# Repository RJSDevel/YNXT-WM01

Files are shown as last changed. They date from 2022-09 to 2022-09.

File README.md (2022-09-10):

# YNXT-WM01
Zigbee Water meter device for YF-S402B counter

The device was created for counting flow and volume passed through kitchen water filter, and it has three independent count channels for measurement, also has buzzer for remind to change filters and extranal load MOSFET for e.g unleak valve enable 
Zigbee2Mqtt supported by [External convector](/YNXT-WM-01.js)

## Z2M and HA Views
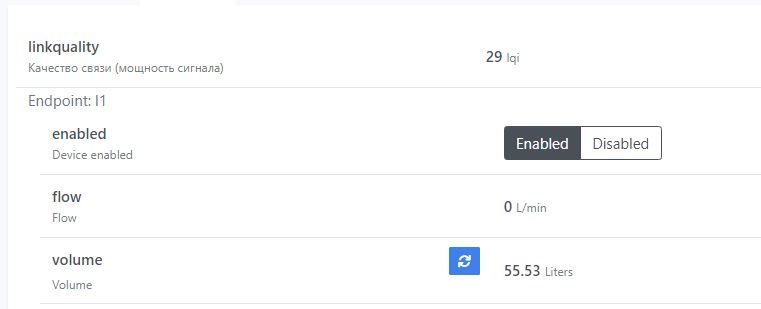
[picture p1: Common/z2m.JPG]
Z2m device

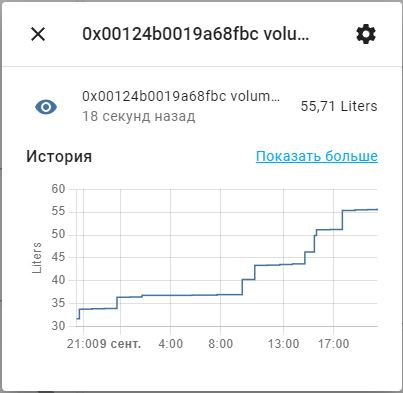
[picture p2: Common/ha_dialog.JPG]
HA Volume Dialog

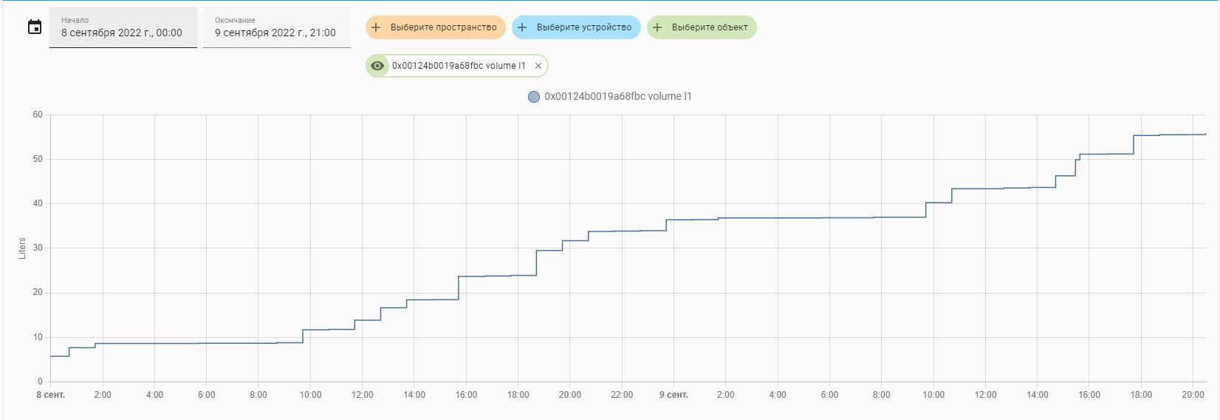
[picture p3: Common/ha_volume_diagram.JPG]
HA Volume Diagram

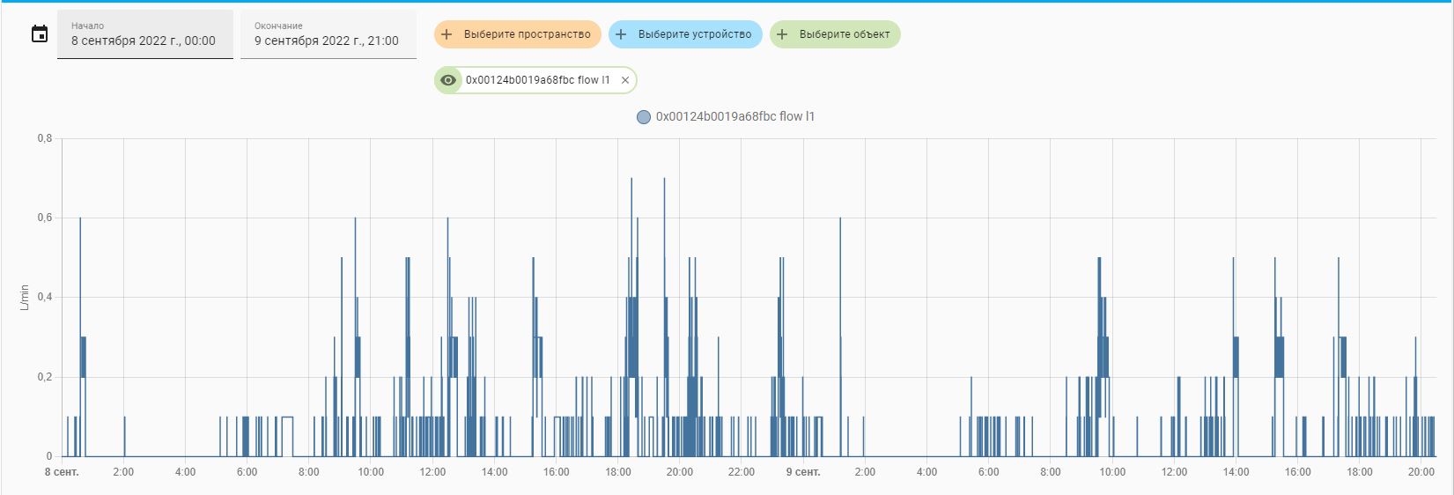
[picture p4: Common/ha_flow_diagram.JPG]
HA Flow Diagram

## Scheme
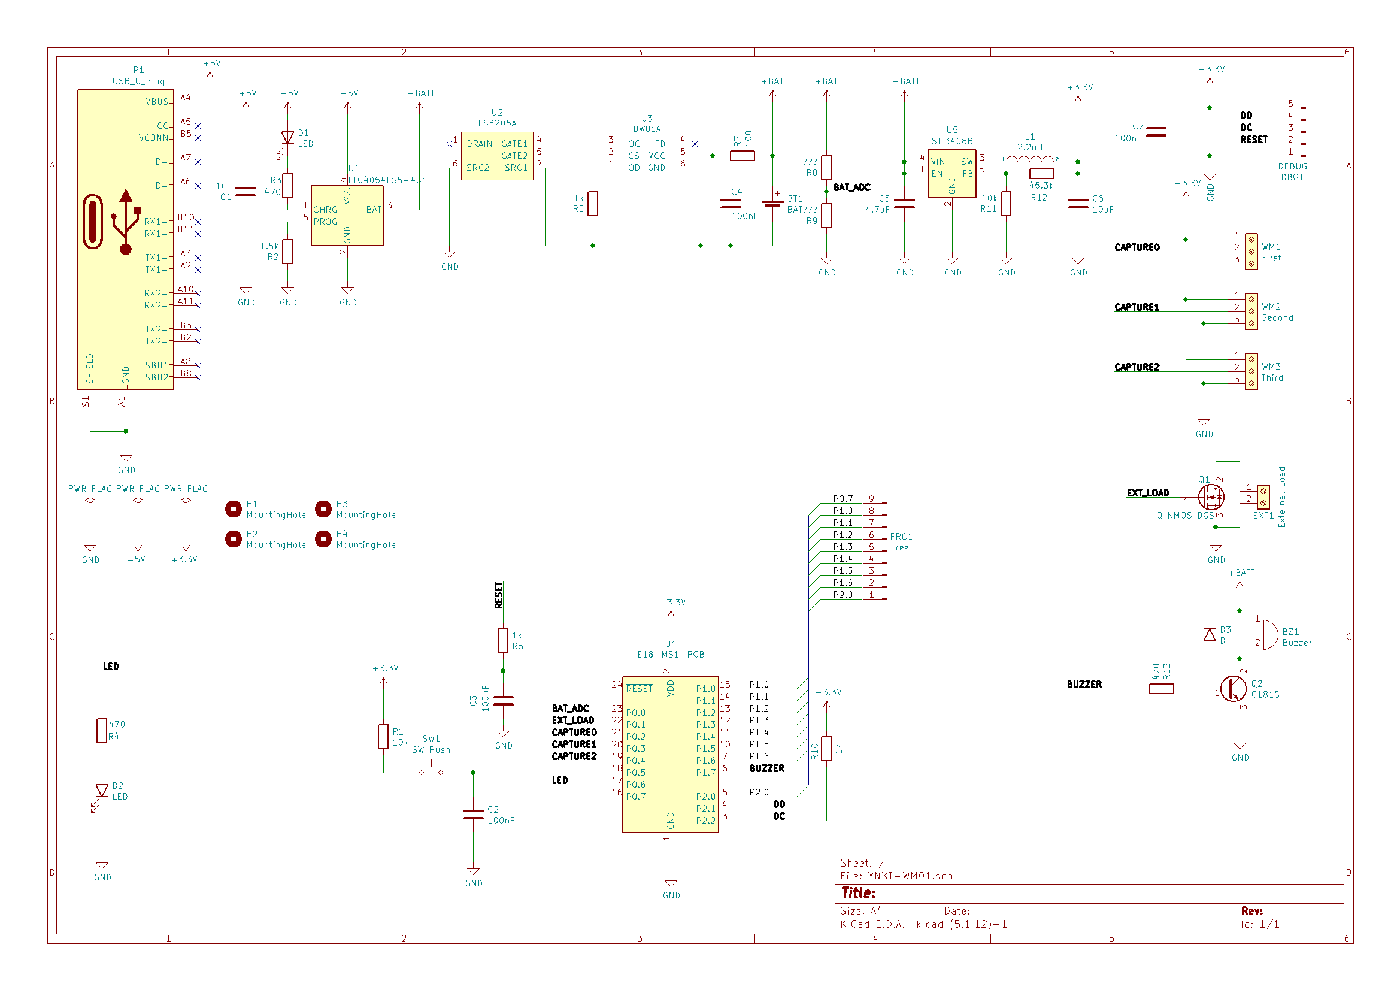
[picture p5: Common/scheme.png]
Scheme

Top
Bottom

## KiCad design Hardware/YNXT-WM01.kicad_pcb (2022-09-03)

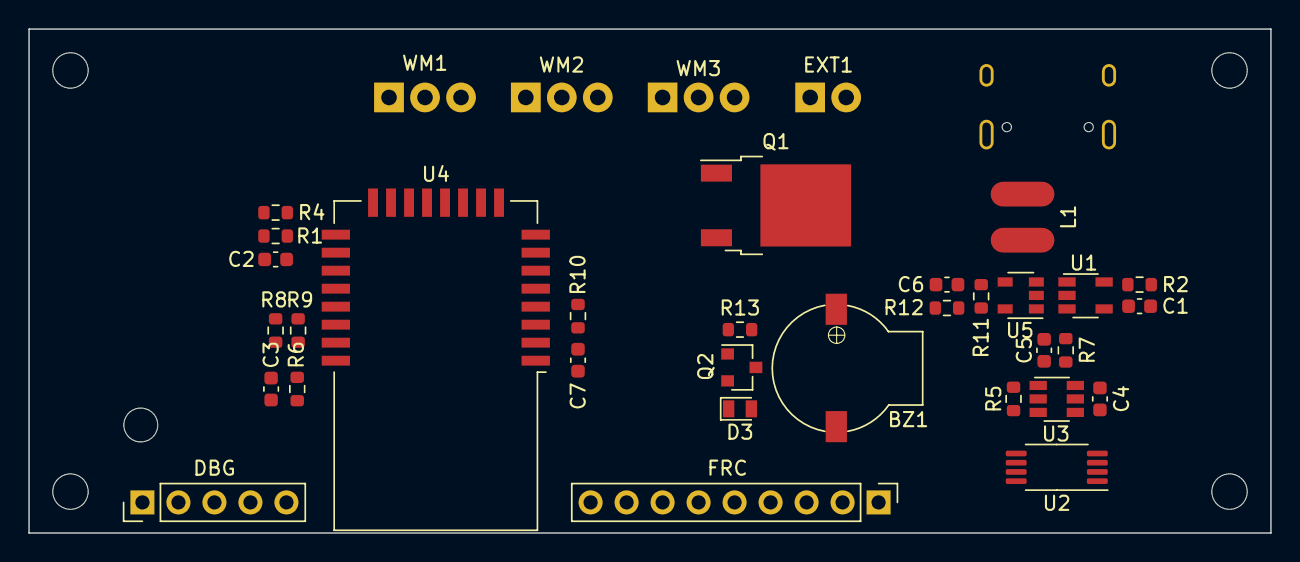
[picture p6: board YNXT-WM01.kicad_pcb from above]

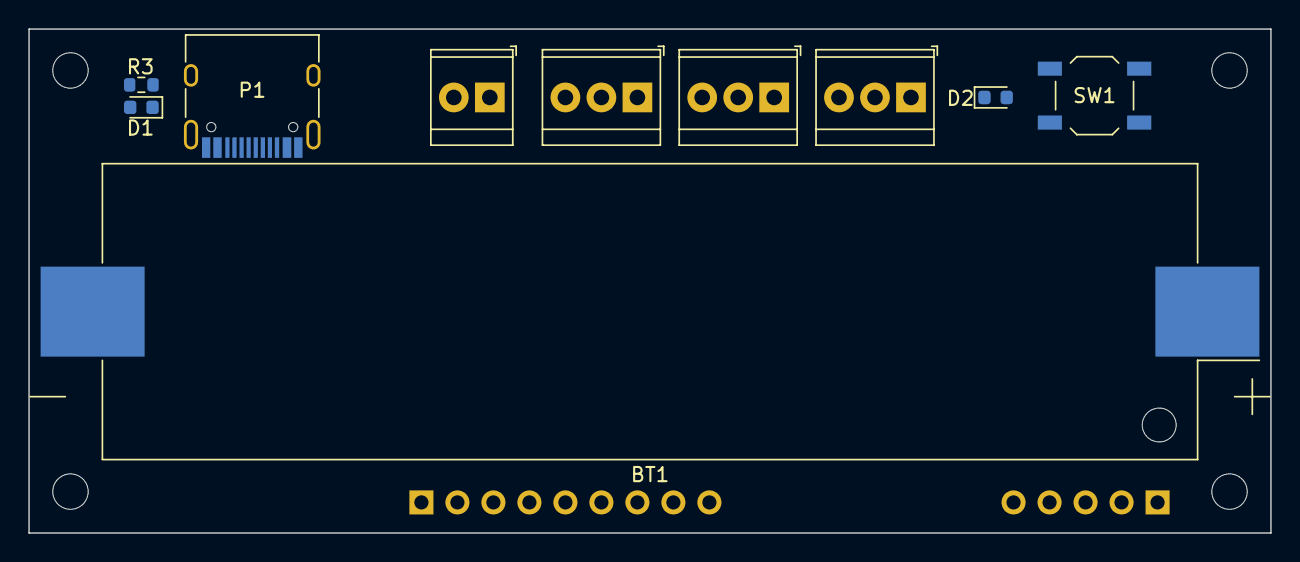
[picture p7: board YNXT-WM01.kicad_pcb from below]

Board: 2 copper layers, 87.6 x 35.6 mm, 45 parts (10 on the bottom side), 41 nets, no tracks yet.

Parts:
BT1: BAT; BatteryHolder_Blossom_1042_1x18650
BZ1: Buzzer; MLT-9032
C1: 1uF; C_0603_1608Metric
C2, C3, C4, C7: 100nF; C_0603_1608Metric
C5: 4.7uF; C_0603_1608Metric
C6: 10uF; C_0603_1608Metric
D1, D2: LED; LED_0603_1608Metric
D3: D; D_MicroMELF
DBG: DEBUG; PinHeader_1x05_P2.54mm_Vertical
EXT1: External Load; TerminalBlock_TE_282834-2_1x02_P2.54mm_Horizontal
FRC: Free; PinHeader_1x09_P2.54mm_Vertical
H1, H2, H3, H4: MountingHole; MountingHole_2.5mm
L1: 2.2uH; CD43
P1: USB_C_Plug; USB_C_Receptacle_HRO_TYPE-C-31-M-12
Q1: Q_NMOS_DGS; TO-252-2
Q2: Q_NPN_BCE; SOT-23
R1, R11: 10k; R_0603_1608Metric
R2: 1.65k; R_0603_1608Metric
R3, R4: 500; R_0603_1608Metric
R5, R6, R10: 1k; R_0603_1608Metric
R7: 100; R_0603_1608Metric
R8, R9: ???; R_0603_1608Metric
R12: 45.3k; R_0603_1608Metric
R13: 470; R_0603_1608Metric
SW1: SW_Push; SW_SPST_TL3342
U1: LTC4054ES5-4.2; TSOT-23-5
U2: FS8205A; TSSOP-8_4.4x3mm_P0.65mm
U3: DW01A; TSOT-23-6
U4: E18-MS1-PCB
U5: STI3408B; SOT-23-5
WM1: First; TerminalBlock_TE_282834-3_1x03_P2.54mm_Horizontal
WM2: Second; TerminalBlock_TE_282834-3_1x03_P2.54mm_Horizontal
WM3: Third; TerminalBlock_TE_282834-3_1x03_P2.54mm_Horizontal

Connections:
+3V3: C6.1, C7.1, DBG.5, L1.2, R1.1, R10.2, R12.2, U4.2, WM1.1, WM2.1, WM3.1
+5V: C1.2, P1.A4, P1.A9, P1.B4, P1.B9, R3.1, U1.4
+BATT: BT1.1, BZ1.1, C5.1, D3.1, R7.2, R8.2, U1.3, U5.1, U5.4
/BAT_ADC: R8.1, R9.2, U4.23
/BUZZER: R13.2, U4.6
/CAPTURE0: U4.21, WM1.2
/CAPTURE1: U4.20, WM2.2
/CAPTURE2: U4.19, WM3.2
/DC: DBG.3, R10.1, U4.3
/DD: DBG.4, U4.4
/EXT_LOAD: Q1.1, U4.22
/KEY: C2.1, SW1.2, U4.18
/LED: R4.2, U4.17
/P0.7: FRC.9, U4.16
/P1.0: FRC.8, U4.15
/P1.1: FRC.7, U4.14
/P1.2: FRC.6, U4.13
/P1.3: FRC.5, U4.12
/P1.4: FRC.4, U4.11
/P1.5: FRC.3, U4.10
/P1.6: FRC.2, U4.7
/P2.0: FRC.1, U4.5
/RESET: DBG.2, R6.2
GND: C1.1, C2.2, C3.1, C5.2, C6.2, C7.2, D2.1, DBG.1, EXT1.2, P1.A1, P1.A12, P1.B1, P1.B12, P1.S1, Q1.3, Q2.3, R2.1, R9.1, R11.1, U1.2, U2.6, U2.7, U4.1, U5.2, WM1.3, WM2.3, WM3.3
unnamed: BT1.2, C4.2, R5.1, U2.2, U2.3, U3.6
unnamed: BZ1.2, D3.2, Q2.2
unnamed: C3.2, R6.1, U4.24
unnamed: C4.1, R7.1, U3.5
unnamed: D1.1, U1.1
unnamed: D1.2, R3.2
unnamed: D2.2, R4.1
unnamed: EXT1.1, Q1.2
unnamed: L1.1, U5.3
unnamed: Q2.1, R13.1
unnamed: R1.2, SW1.1
unnamed: R2.2, U1.5
unnamed: R5.2, U3.2
unnamed: R11.2, R12.1, U5.5
unnamed: U2.1, U2.8
unnamed: U2.4, U3.1
unnamed: U2.5, U3.3

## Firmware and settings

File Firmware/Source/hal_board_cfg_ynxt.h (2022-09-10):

/**************************************************************************************************
  Filename:       hal_board_cfg.h
  Revised:        $Date: 2015-02-17 14:17:44 -0800 (Tue, 17 Feb 2015) $
  Revision:       $Revision: 42683 $

  Description:    Declarations for the CC2530EM used on the SmartRF05EB.


  Copyright 2009-2015 Texas Instruments Incorporated. All rights reserved.

  IMPORTANT: Your use of this Software is limited to those specific rights
  granted under the terms of a software license agreement between the user
  who downloaded the software, his/her employer (which must be your employer)
  and Texas Instruments Incorporated (the "License"). You may not use this
  Software unless you agree to abide by the terms of the License. The License
  limits your use, and you acknowledge, that the Software may not be modified,
  copied or distributed unless embedded on a Texas Instruments microcontroller
  or used solely and exclusively in conjunction with a Texas Instruments radio
  frequency transceiver, which is integrated into your product. Other than for
  the foregoing purpose, you may not use, reproduce, copy, prepare derivative
  works of, modify, distribute, perform, display or sell this Software and/or
  its documentation for any purpose.

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
  Should you have any questions regarding your right to use this Software,
  contact Texas Instruments Incorporated at www.TI.com.
**************************************************************************************************/

#ifndef HAL_BOARD_CFG_H
#define HAL_BOARD_CFG_H


/* ------------------------------------------------------------------------------------------------
 *                                           Includes
 * ------------------------------------------------------------------------------------------------
 */

#include "hal_mcu.h"
#include "hal_defs.h"
#include "hal_types.h"

/* ------------------------------------------------------------------------------------------------
 *                                       CC2590/CC2591 support
 *
 *                        Define HAL_PA_LNA_CC2590 if CC2530+CC2590EM is used
 *                        Define HAL_PA_LNA if CC2530+CC2591EM is used
 *                        Note that only one of them can be defined
 * ------------------------------------------------------------------------------------------------
 */
#define xHAL_PA_LNA
#define xHAL_PA_LNA_CC2590
#define xHAL_PA_LNA_SE2431L
#define xHAL_PA_LNA_CC2592


/* ------------------------------------------------------------------------------------------------
 *                                       Board Indentifier
 *
 *      Define the Board Identifier to HAL_BOARD_CC2530EB_REV13 for SmartRF05 EB 1.3 board
 * ------------------------------------------------------------------------------------------------
 */

#if !defined (HAL_BOARD_CC2530EB_REV17) && !defined (HAL_BOARD_CC2530EB_REV13)
#define HAL_BOARD_CC2530EB_REV17
#endif

/* ------------------------------------------------------------------------------------------------
 *                                          Clock Speed
 * ------------------------------------------------------------------------------------------------
 */

#define HAL_CPU_CLOCK_MHZ     32

/* This flag should be defined if the SoC uses the 32MHz crystal
 * as the main clock source (instead of DCO).
 */
#define HAL_CLOCK_CRYSTAL

/* 32 kHz clock source select in CLKCONCMD */
#if !defined (OSC32K_CRYSTAL_INSTALLED) || (defined (OSC32K_CRYSTAL_INSTALLED) && (OSC32K_CRYSTAL_INSTALLED == TRUE))
  #define OSC_32KHZ  0x00 /* external 32 KHz xosc */
#else
  #define OSC_32KHZ  0x80 /* internal 32 KHz rcosc */
#endif

#define HAL_CLOCK_STABLE()    st( while (CLKCONSTA != (CLKCONCMD_32MHZ | OSC_32KHZ)); )

/* ------------------------------------------------------------------------------------------------
 *                                       LED Configuration
 * ------------------------------------------------------------------------------------------------
 */

#define HAL_LED_BLINK_DELAY()   st( { volatile uint32 i; for (i=0; i<0x5800; i++) { }; } )

/* 1 - LED status */
#define LED1_BV           BV(6)
#define LED1_SBIT         P0_6
#define LED1_DDR          P0DIR
#define LED1_POLARITY     ACTIVE_HIGH

#define LED2_BV           BV(1)
#define LED2_SBIT         P0_1
#define LED2_DDR          P0DIR
#define LED2_POLARITY     ACTIVE_HIGH

/* ------------------------------------------------------------------------------------------------
 *                                    Push Button Configuration
 * ------------------------------------------------------------------------------------------------
 */

#define ACTIVE_LOW        !
#define ACTIVE_HIGH       !!    /* double negation forces result to be '1' */
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

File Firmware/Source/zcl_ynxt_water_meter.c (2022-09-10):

/**************************************************************************************************
Filename:       zcl_genericapp.c
Revised:        $Date: 2014-10-24 16:04:46 -0700 (Fri, 24 Oct 2014) $
Revision:       $Revision: 40796 $


Description:    Zigbee Cluster Library - sample device application.


Copyright 2006-2014 Texas Instruments Incorporated. All rights reserved.

IMPORTANT: Your use of this Software is limited to those specific rights
granted under the terms of a software license agreement between the user
who downloaded the software, his/her employer (which must be your employer)
and Texas Instruments Incorporated (the "License").  You may not use this
Software unless you agree to abide by the terms of the License. The License
limits your use, and you acknowledge, that the Software may not be modified,
copied or distributed unless embedded on a Texas Instruments microcontroller
or used solely and exclusively in conjunction with a Texas Instruments radio
frequency transceiver, which is integrated into your product.  Other than for
the foregoing purpose, you may not use, reproduce, copy, prepare derivative
works of, modify, distribute, perform, display or sell this Software and/or
its documentation for any purpose.

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
Should you have any questions regarding your right to use this Software,
contact Texas Instruments Incorporated at www.TI.com.
**************************************************************************************************/

/*********************************************************************
This application is a template to get started writing an application
from scratch.

Look for the sections marked with "YNXT_WATER_METER_TODO" to add application
specific code.

Note: if you would like your application to support automatic attribute
reporting, include the BDB_REPORTING compile flag.
*********************************************************************/

/*********************************************************************
* INCLUDES
*/
#include "ZComDef.h"
#include "OSAL.h"
#include "OSAL_PwrMgr.h"
#include "AF.h"
#include "ZDApp.h"
#include "ZDObject.h"
#include "MT_SYS.h"

#include "nwk_util.h"

#include "zcl.h"
#include "zcl_general.h"
#include "zcl_ha.h"
#include "zcl_diagnostic.h"
#include "zcl_se.h"
#include "zcl_ms.h"
#include "zcl_ynxt_water_meter.h"

#include "bdb.h"
#include "bdb_interface.h"
#include "gp_interface.h"

#include "onboard.h"

/* HAL */
#include "hal_led.h"
#include "hal_key.h"
#include "hal_drivers.h"

#include "buzzer.h"

/*********************************************************************
* MACROS
*/


/*********************************************************************
* CONSTANTS
*/


/*********************************************************************
* TYPEDEFS
*/

/*********************************************************************
* GLOBAL VARIABLES
*/
byte zclYnxtWaterMeter_TaskID;


/*********************************************************************
* GLOBAL FUNCTIONS
*/

/*********************************************************************
* LOCAL VARIABLES
*/
uint8 gPermitDuration = 0;    // permit joining default to disabled

devStates_t zclYnxtWaterMeter_NwkState = DEV_INIT;

static uint32 seqNum = 0;

/*********************************************************************
* LOCAL FUNCTIONS
*/
static void zclYnxtWaterMeter_load_nvm(void);

static void zclYnxtWaterMeter_HandleKeys(byte keys);

static void zclYnxtWaterMeter_BasicResetCB_EP_First( void );
static void zclYnxtWaterMeter_BasicResetCB_EP_Second( void );
static void zclYnxtWaterMeter_BasicResetCB_EP_Third( void );
static void zclYnxtWaterMeter_BasicResetCB( void );

static void zclYnxtWaterMeter_OnOffCB( uint8 cmd );

static void zclYnxtWaterMeter_ProcessIdentifyTimeChange( uint8 endpoint );

static void zclYnxtWaterMeter_BindNotification( bdbBindNotificationData_t *data );

static void zclYnxtWaterMeter_ProcessCommissioningStatus(bdbCommissioningModeMsg_t *bdbCommissioningModeMsg);


// Functions to process ZCL Foundation incoming Command/Response messages
static void zclYnxtWaterMeter_ProcessIncomingMsg( zclIncomingMsg_t *msg );
#ifdef ZCL_READ
static uint8 zclYnxtWaterMeter_ProcessInReadRspCmd( zclIncomingMsg_t *pInMsg );
#endif
#ifdef ZCL_WRITE
static uint8 zclYnxtWaterMeter_ProcessInWriteRspCmd( zclIncomingMsg_t *pInMsg );
#endif
static uint8 zclYnxtWaterMeter_ProcessInDefaultRspCmd( zclIncomingMsg_t *pInMsg );
#ifdef ZCL_DISCOVER
static uint8 zclYnxtWaterMeter_ProcessInDiscCmdsRspCmd( zclIncomingMsg_t *pInMsg );
static uint8 zclYnxtWaterMeter_ProcessInDiscAttrsRspCmd( zclIncomingMsg_t *pInMsg );
static uint8 zclYnxtWaterMeter_ProcessInDiscAttrsExtRspCmd( zclIncomingMsg_t *pInMsg );
#endif

static void zclSampleApp_BatteryWarningCB( uint8 voltLevel);

static void zclYnxtWaterMeter_ReportWaterFlow( uint8 endPoint, uint16* value );

static ZStatus_t zclYnxtAuthorizeDirtyHackUpdateEnableStatesCB( afAddrType_t *srcAddr, zclAttrRec_t *pAttr, uint8 oper );

void prepare_for_wait_start_measure(void);
void start_measuring(void);

void halProcessKeyInterrupt(void);

/*********************************************************************
* ZCL General Profile Callback table
*/
static zclGeneral_AppCallbacks_t zclYnxtWaterMeter_CmdCallbacks_EP_First =
{
  zclYnxtWaterMeter_BasicResetCB_EP_First,      // Basic Cluster Reset command
  NULL,                                         // Identify Trigger Effect command
  NULL,                                         // On/Off cluster commands
  NULL,                                         // On/Off cluster enhanced command Off with Effect
  NULL,                                         // On/Off cluster enhanced command On with Recall Global Scene
  NULL,                                         // On/Off cluster enhanced command On with Timed Off
  NULL,                                         // RSSI Location command
  NULL                                          // RSSI Location Response command
};
static zclGeneral_AppCallbacks_t zclYnxtWaterMeter_CmdCallbacks_EP_Second =
{
  zclYnxtWaterMeter_BasicResetCB_EP_Second,     // Basic Cluster Reset command
  NULL,                                         // Identify Trigger Effect command
  NULL,                                         // On/Off cluster commands
  NULL,                                         // On/Off cluster enhanced command Off with Effect
  NULL,                                         // On/Off cluster enhanced command On with Recall Global Scene
  NULL,                                         // On/Off cluster enhanced command On with Timed Off
  NULL,                                         // RSSI Location command
  NULL                                          // RSSI Location Response command
};
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

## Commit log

2022-09-04 Fix Firmware project compile issues, fix software save NVM states and enter to sleep mode
    [zcl_ynxt_water_meter.c]
2022-09-05 Add reset volume, update enable device
    [zcl_ynxt_water_meter.c, zcl_ynxt_water_meter.h]
2022-09-07 Remade count impulse to liters, fix disapperearance of volume
    [hal_board_cfg_ynxt.h, zcl_ynxt_water_meter.c]
2022-09-09 Add reset volume for each channel, edit scheme elements values
    [YNXT-WM01.sch]
